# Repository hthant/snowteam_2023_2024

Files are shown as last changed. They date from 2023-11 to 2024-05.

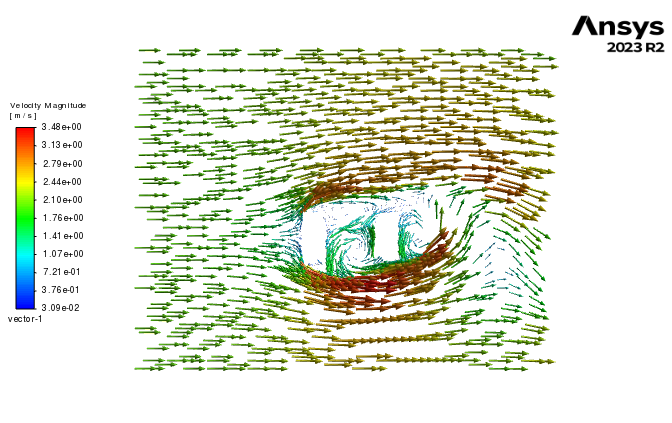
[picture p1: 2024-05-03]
CFD/DPM/DPM 5/DPM Attempt 5_files/progress_files/dp0/FFF-1/Fluent/particle-tracks-1.png

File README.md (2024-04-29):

# Snowteam 2023/2024
Snowflake Team Project Files AY2023_2024

### Summary
  The Machine Learning, Sensing, and Image Processing for Snow Research Senior Design team (Snowflake team) is first repairing the snow measurement and analysis system (SMAS). The SMAS is a device that gathers information on snowflakes and analyzes them using machine learning. This gathers important data including the fall speed of the snowflake and its approximate mass, volume, and density while a snowflake is actively falling. This is accomplished through the high-speed cameras and flashes that are triggered through a system of laser sensors. This data needs to be collected outdoors in harsh winter conditions, so the device must be waterproof and operate at very cold temperatures. This also brings up electrical issues such as providing it with a constant power supply and internet so it continually collects and analyzes data from winter storms. As this is an ongoing project, there is an existing device that is being repaired and improved on from previous years. Additionally, the team is planning the next generation of the SMAS that will be an improvement on the current version. This improvement mainly focuses on a better mechanical design to increase the accuracy of fall speed measurements, as well as improvements on electrical and computer hardware.

### Fall 2023 Semester Team: 
- **Noah Johnson** 
- **Connor Mackell**
- **Kyle Nilsson** 
- **Lauren Rickert**
- **Ryan Zonefeld**

### Spring 2024 Semester Team:
- **Noah Johnson** 
- **Connor Mackell**
- **Kyle Nilsson** 
- **Lauren Rickert**
- **Isai Garcia Zamora**
- **James Sawyer**

### Github Resources
[slides](https://docs.google.com/presentation/d/1HG5fEbkIR5e4xt7H8ZSW351dlRXp_NinHjw-bwELlns/edit?usp=sharing)

[meeting recording](https://drive.google.com/file/d/1aQnVjBFZ8f4g6_dN77DBQdKdTyLpH9qw/view?usp=drive_link)

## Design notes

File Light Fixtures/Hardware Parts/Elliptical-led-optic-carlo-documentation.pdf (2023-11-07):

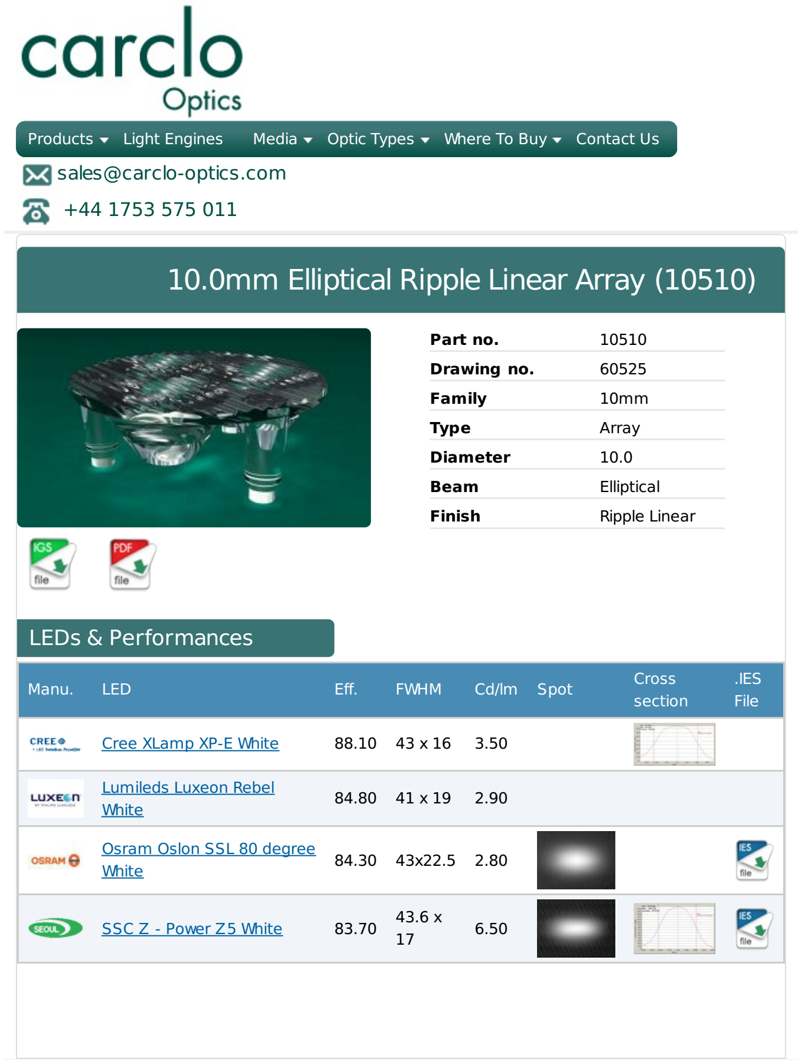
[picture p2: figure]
sales@carclo-optics.com; Part no.; Drawing no.; Family; Type; Array; Diameter; Beam; Elliptical; Finish; Ripple Linear; LEDs & Performances; Manu.; LED; Eff.; FWHM; Cd/lm Spot; Cross section; .IES File; Cree XLamp XP-E White; Lumileds Luxeon Rebel White; Osram Oslon SSL 80 degree White; SSC Z - Power Z5 White; Products; Light Engines; Media; Optic Types; Where To Buy; Contact Us

# 10.0mm Elliptical Ripple Linear Array (10510)

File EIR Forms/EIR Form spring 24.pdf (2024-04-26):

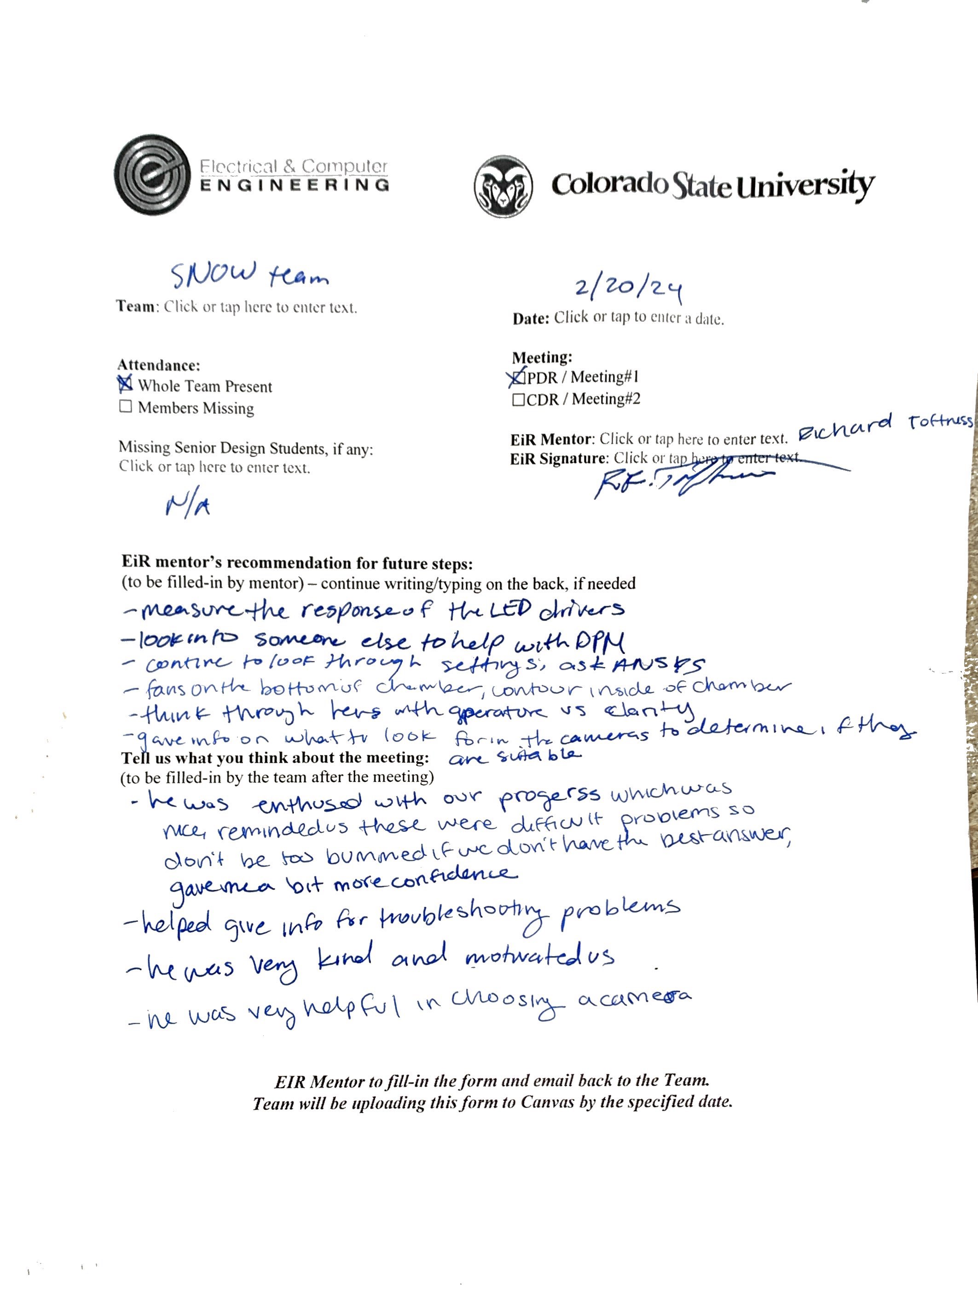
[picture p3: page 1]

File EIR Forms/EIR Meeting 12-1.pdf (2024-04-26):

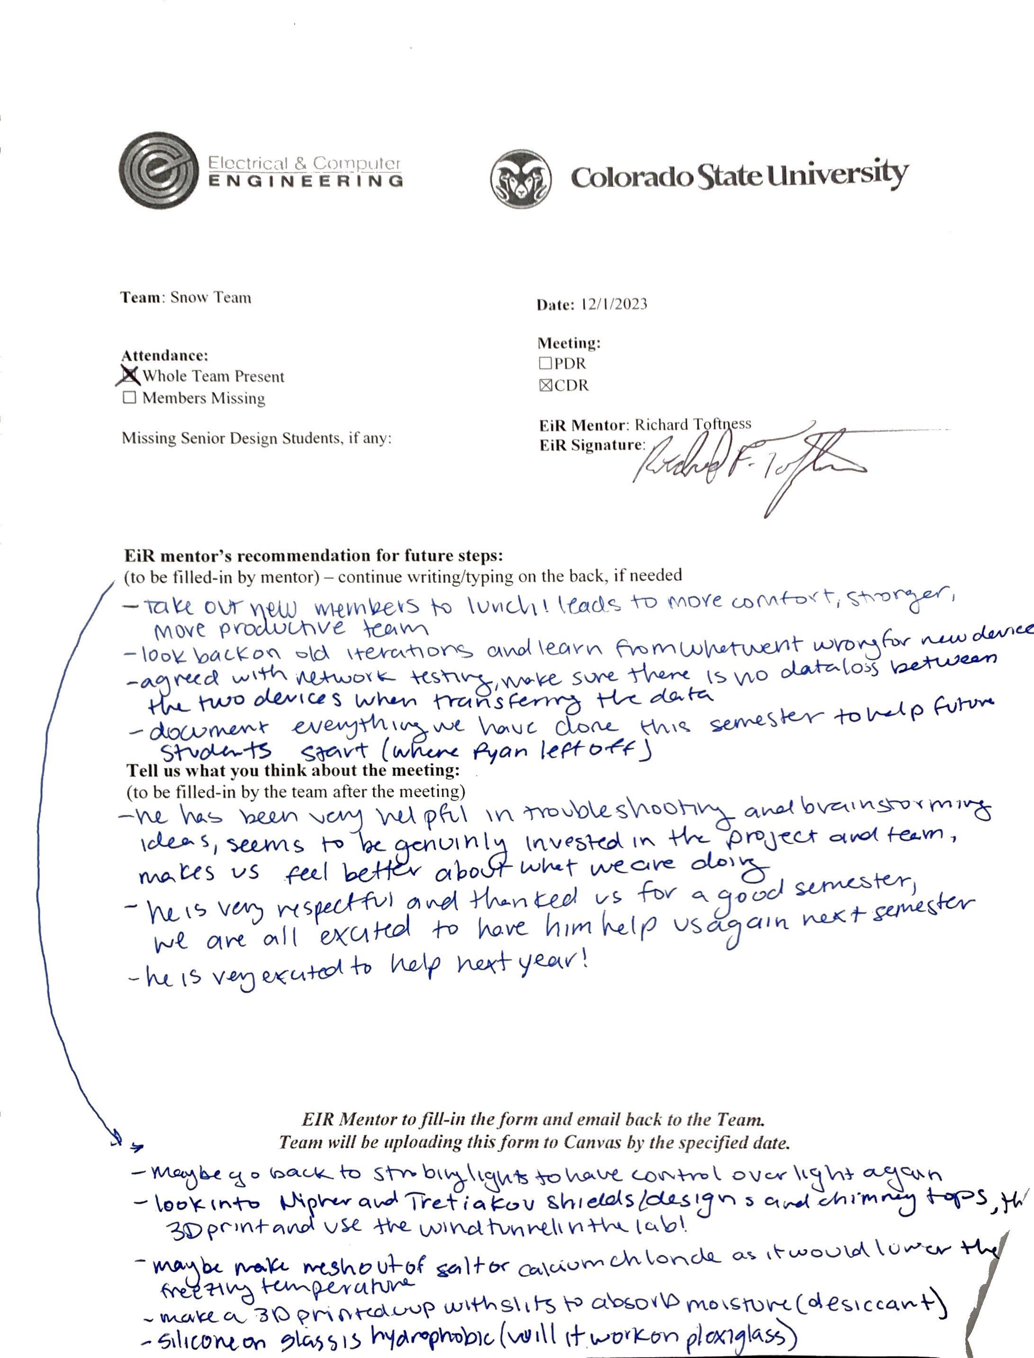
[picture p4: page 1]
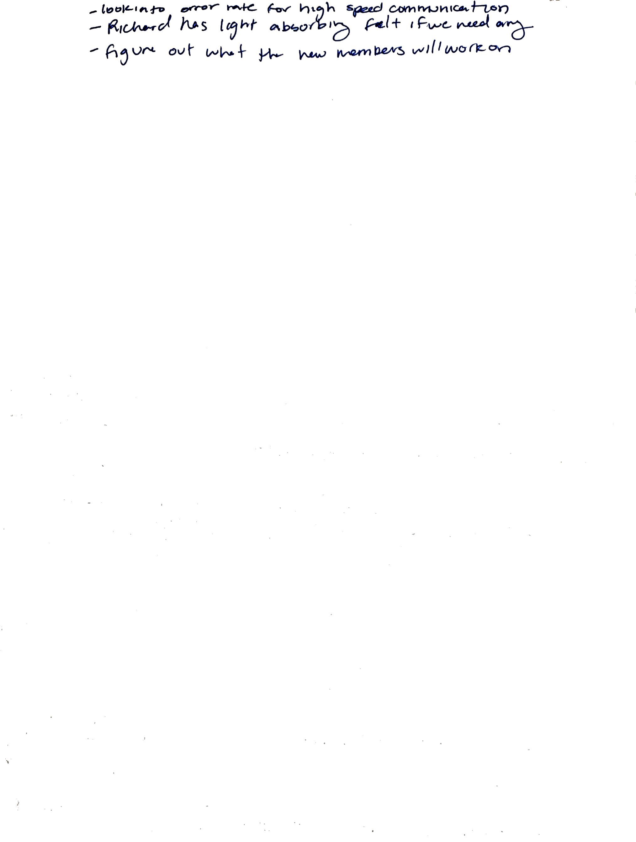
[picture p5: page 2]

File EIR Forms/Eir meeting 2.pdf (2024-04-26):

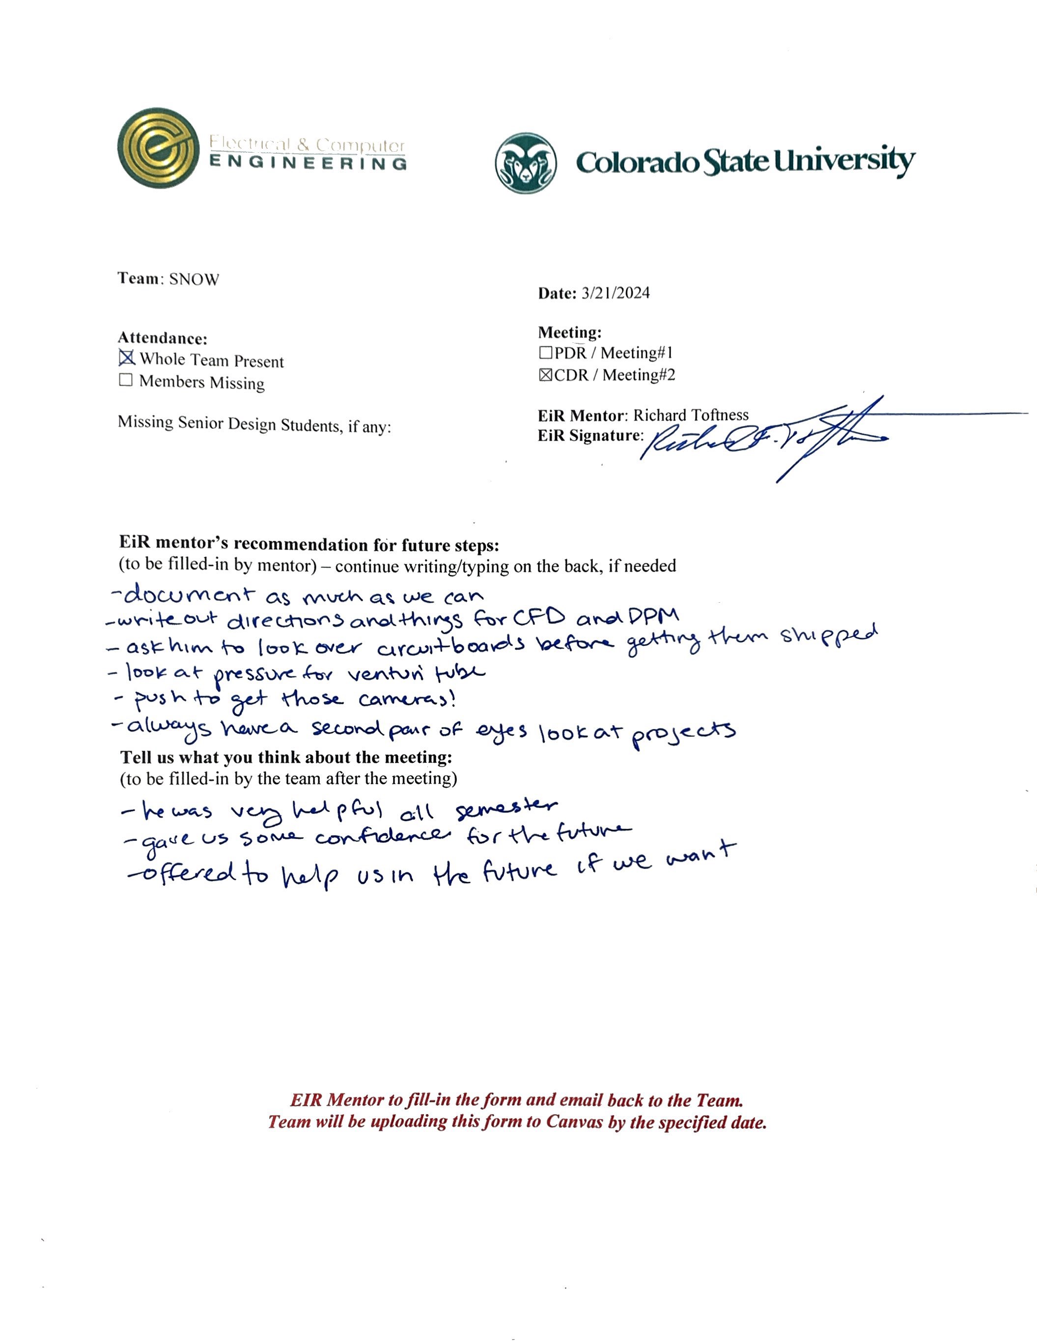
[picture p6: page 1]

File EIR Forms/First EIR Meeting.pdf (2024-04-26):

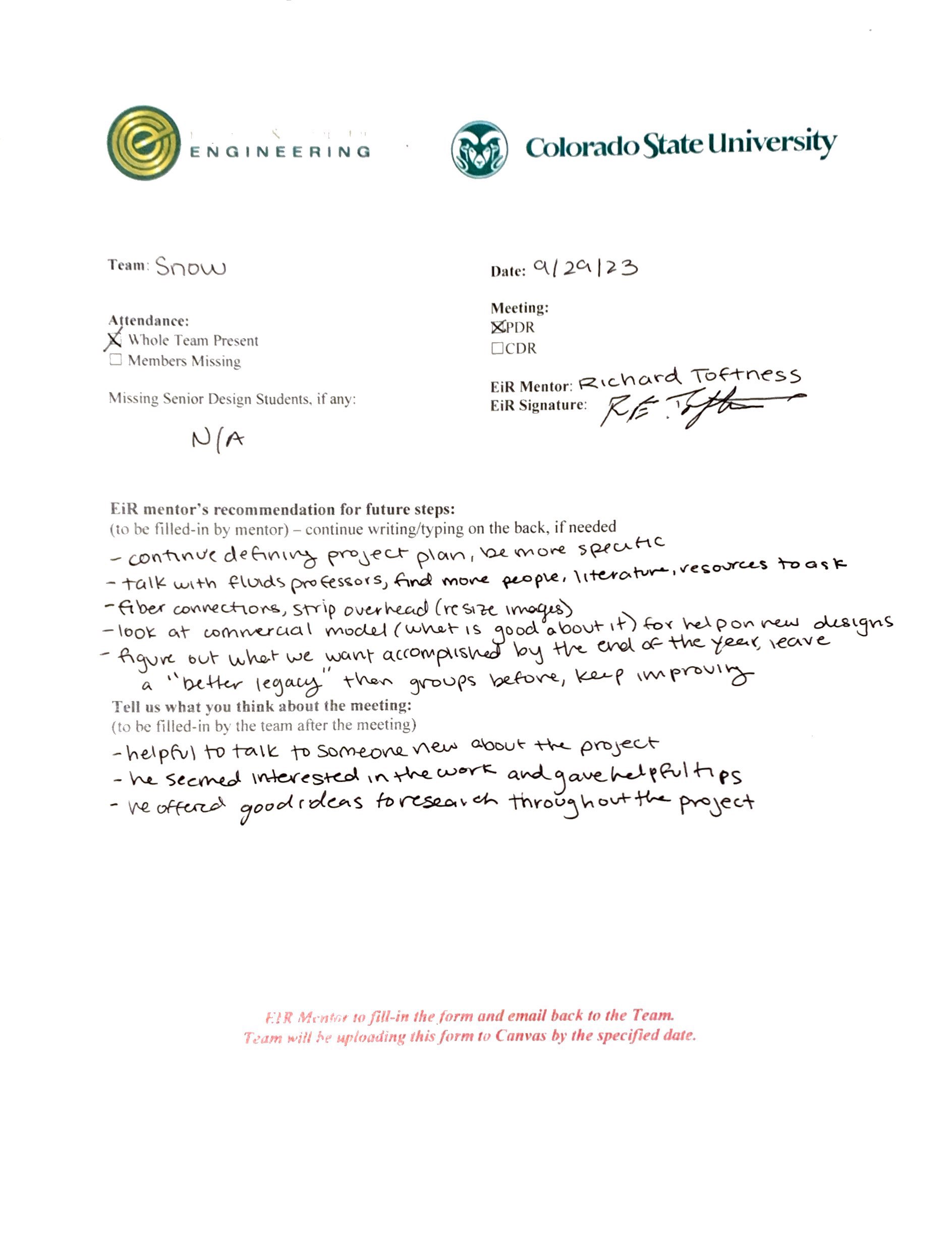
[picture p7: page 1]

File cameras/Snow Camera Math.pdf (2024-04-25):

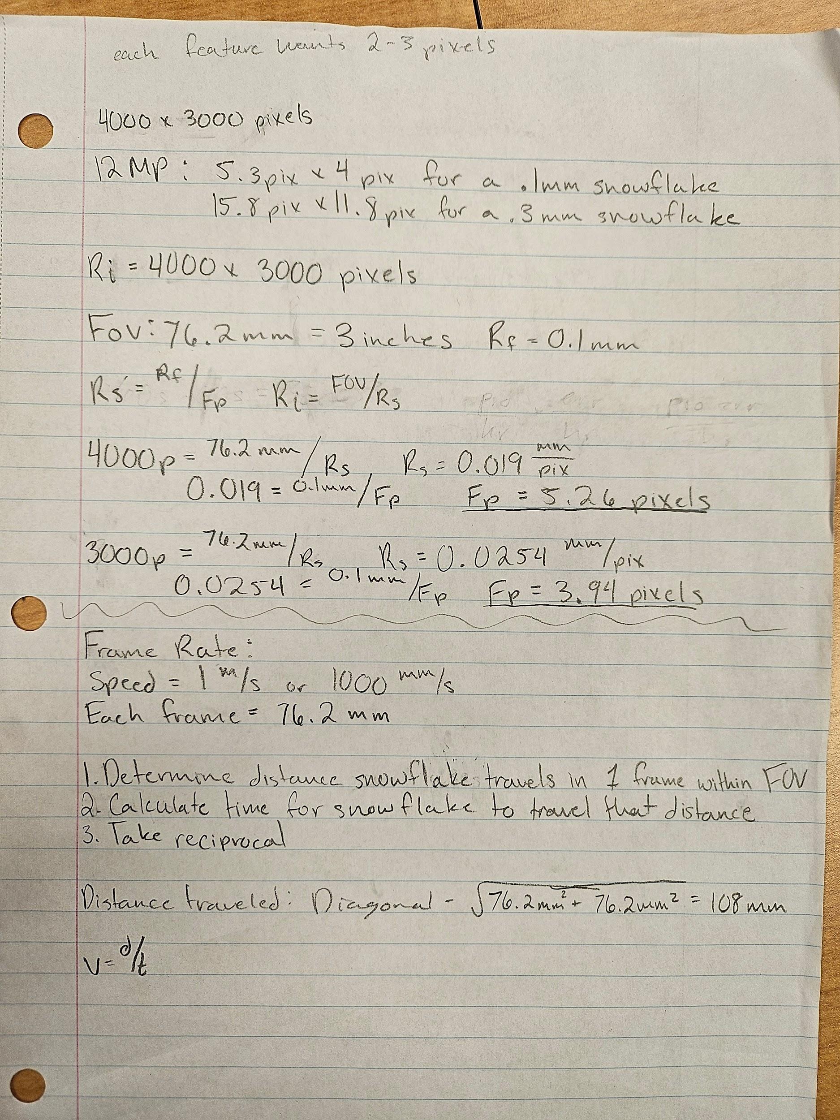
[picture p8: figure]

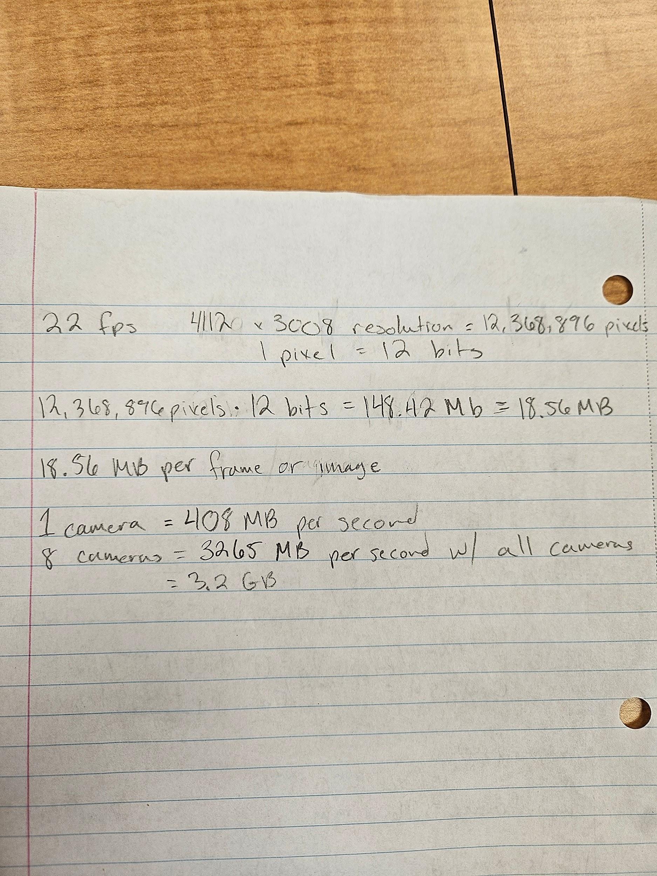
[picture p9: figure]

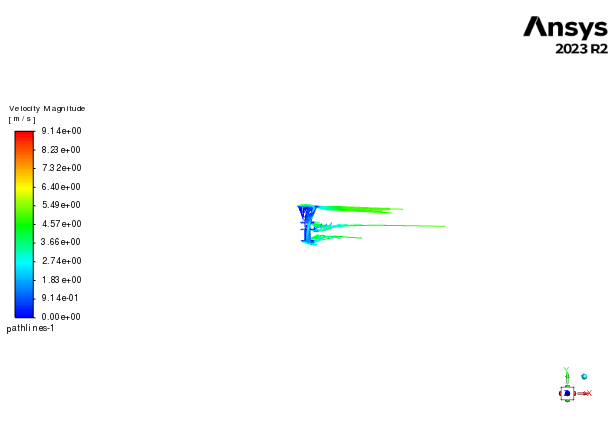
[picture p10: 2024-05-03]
CFD/Conical SMAS Designs/Workbench/Partial_files/progress_files/dp0/FFF-1/Fluent/pathlines-1.png

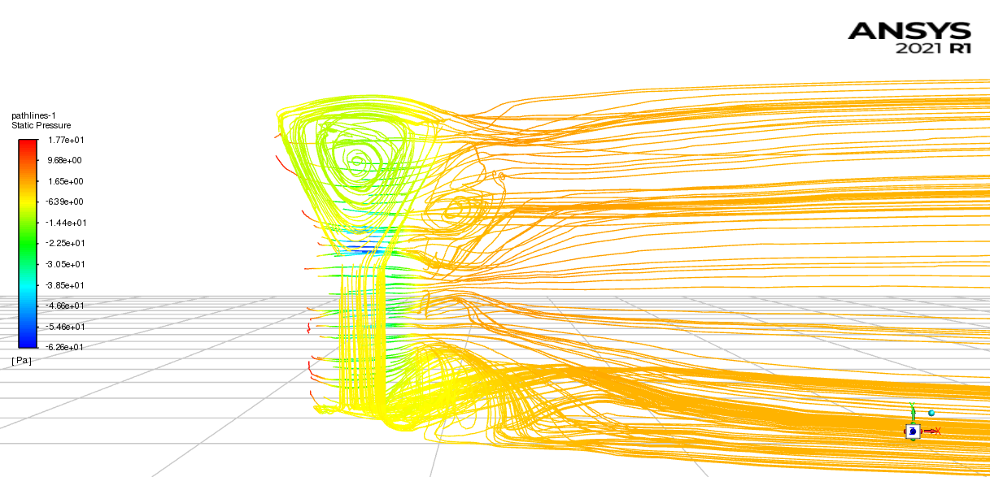
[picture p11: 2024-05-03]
CFD/Conical SMAS Designs/Workbench/Conical_25_degree_SYM_files/dp0/FFF/MECH/Conical_25_degree_SYM_Pressure.png

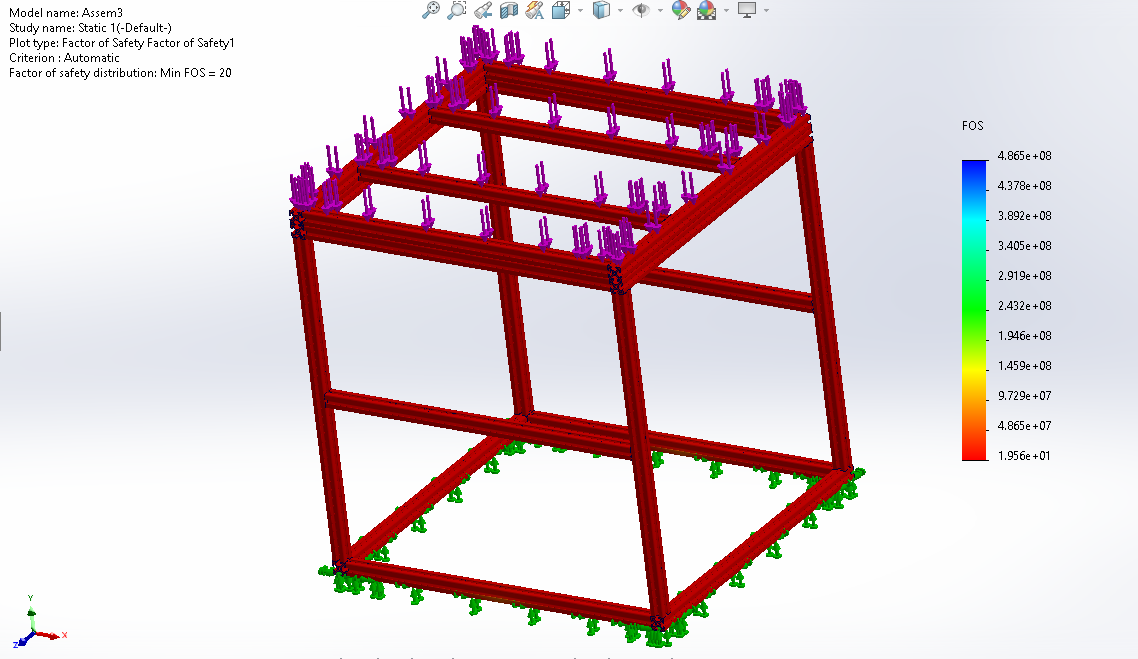
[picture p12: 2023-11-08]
solidworks_senior_design/safetyfactor8020_1.0inch.PNG

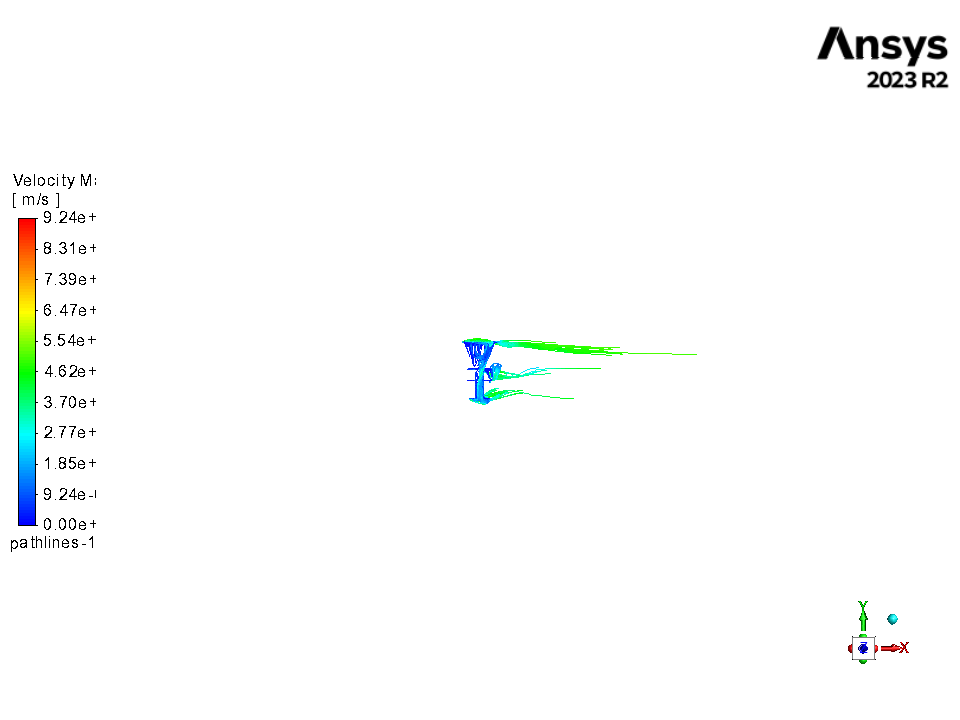
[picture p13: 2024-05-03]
CFD/Conical SMAS Designs/Workbench/Conical_20_degree_SYM_files/progress_files/dp0/FFF-1/Fluent/pathlines-1.png

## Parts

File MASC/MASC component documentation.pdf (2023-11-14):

Part types and numbers:
3 48 V power supplies : CFM70S480
12 V power supply: CFM70S120
Datasheet: https://www.componentsbureau.com/assets/product_files/cfm70s_datasheet.pdf Female housings for power supplies: VHR-3N & VHR-4N
Datasheet: https://www.jst-mfg.com/product/pdf/eng/eVH.pdf
Crimps for power supplies: SVH-41T-P1.1
Connecter for 12V power splitter: 0397730002
Datasheet: https://tools.molex.com/pdm_docs/sd/397730002_sd.pdf 22 AWG wire for power supply connections

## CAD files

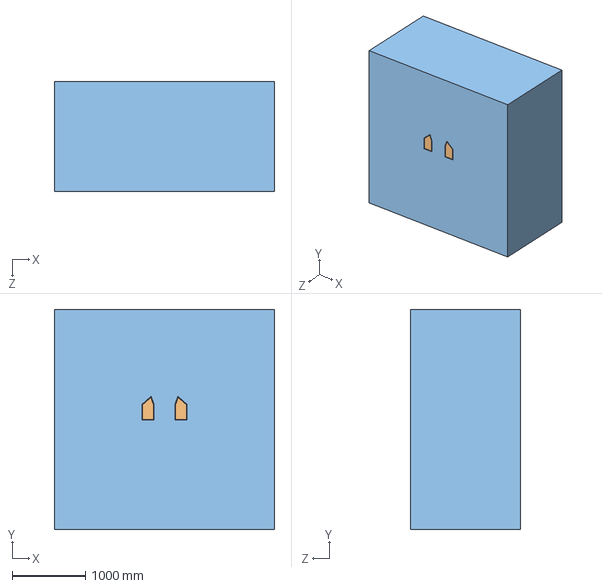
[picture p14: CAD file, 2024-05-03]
CFD/FebruaryBasicDesign/newdesignstraightupfullangle.STEP
3000.0 x 3000.0 x 1500.0 mm

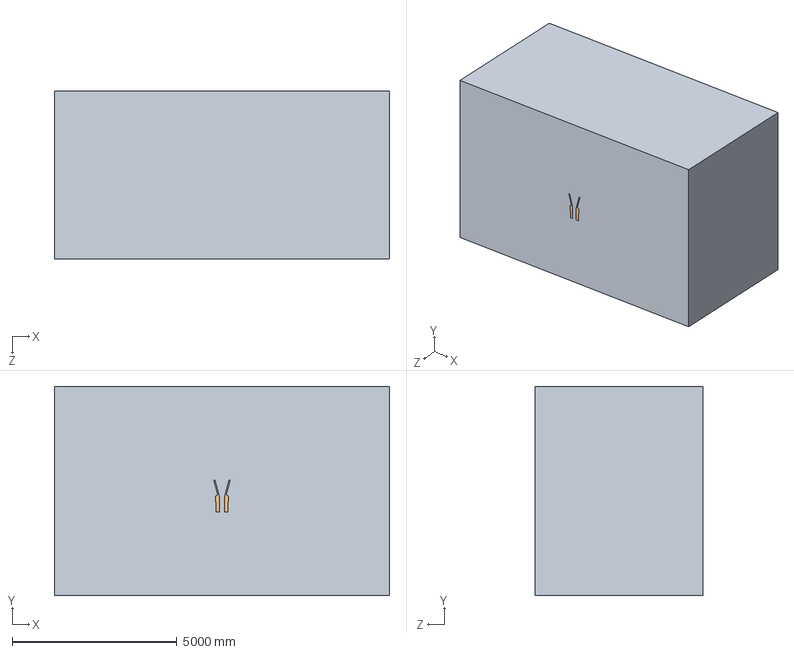
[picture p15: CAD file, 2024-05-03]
CFD/Conical SMAS Designs/Solidworks/Conical_15_degree_SYM.STEP
10160.0 x 6350.0 x 5080.0 mm

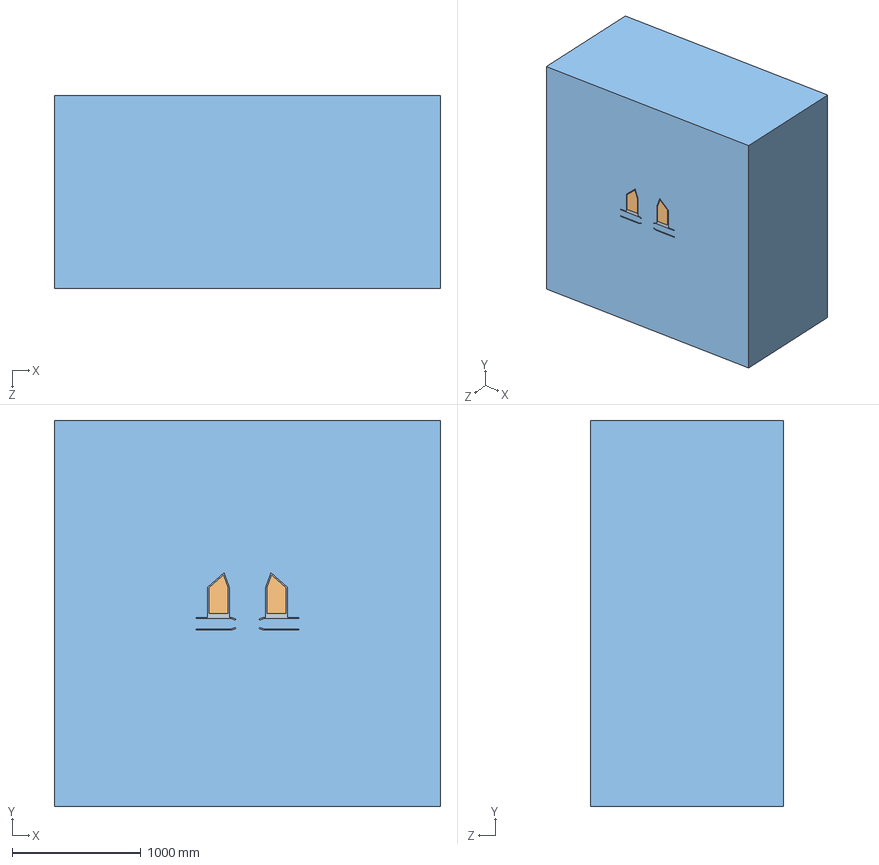
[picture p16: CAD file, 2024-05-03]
CFD/Venturi Tube/VenturiTube2.STEP
3000.0 x 3000.0 x 1500.0 mm

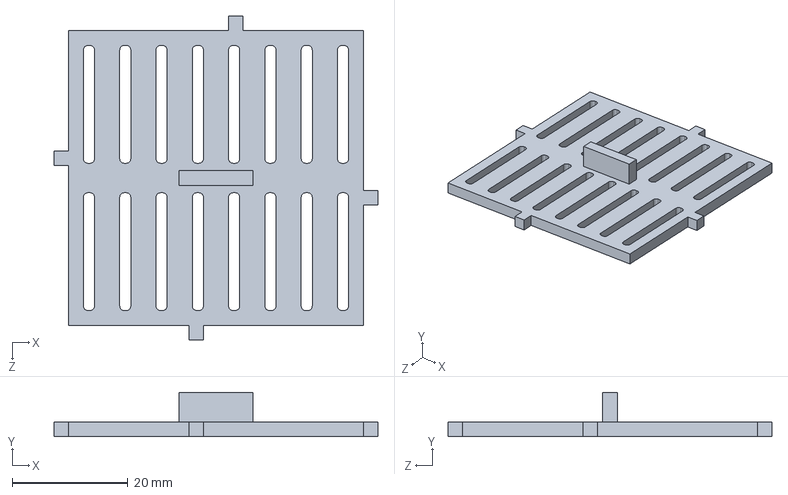
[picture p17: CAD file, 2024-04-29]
Desiccant Box/DesiccantBoxLid.SLDPRT
55.9 x 7.62 x 55.9 mm

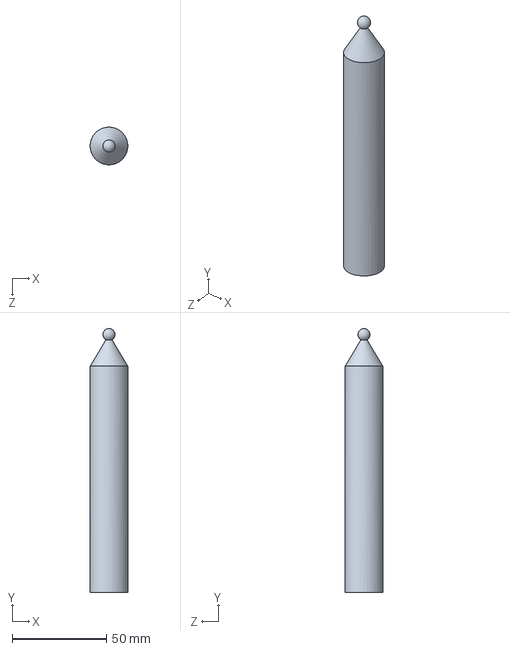
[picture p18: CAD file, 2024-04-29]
LED Pen/BasicPen.SLDPRT
20.0 x 140.0 x 20.0 mm

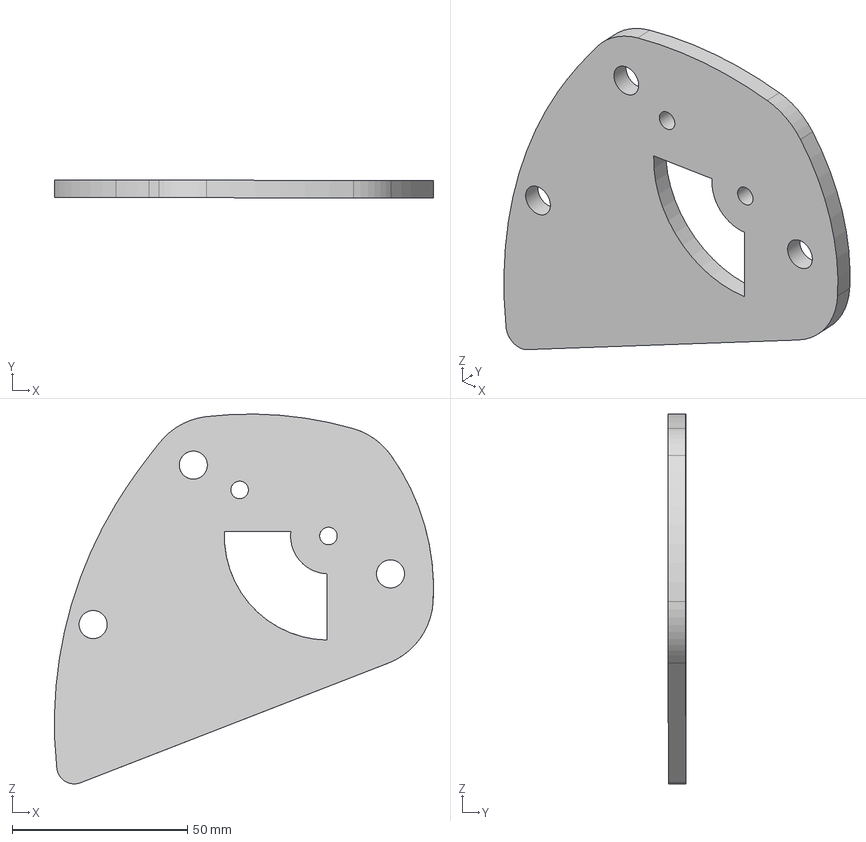
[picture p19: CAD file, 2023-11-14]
Light Fixtures/LED Bracket CAD Files/Diagnal LED Bracket - 1 side.step
108.0 x 5.26 x 105.4 mm

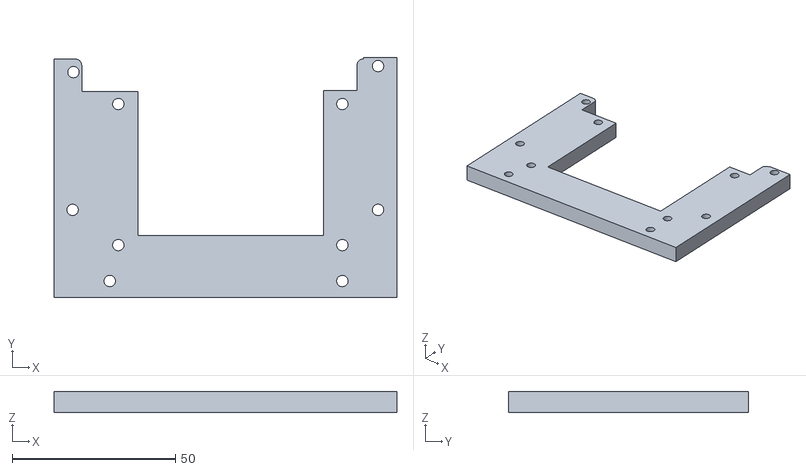
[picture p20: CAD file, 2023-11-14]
MASC/3D drawings/Power_supply_3rd_try v3.stl
105.0 x 73.4 x 6.50

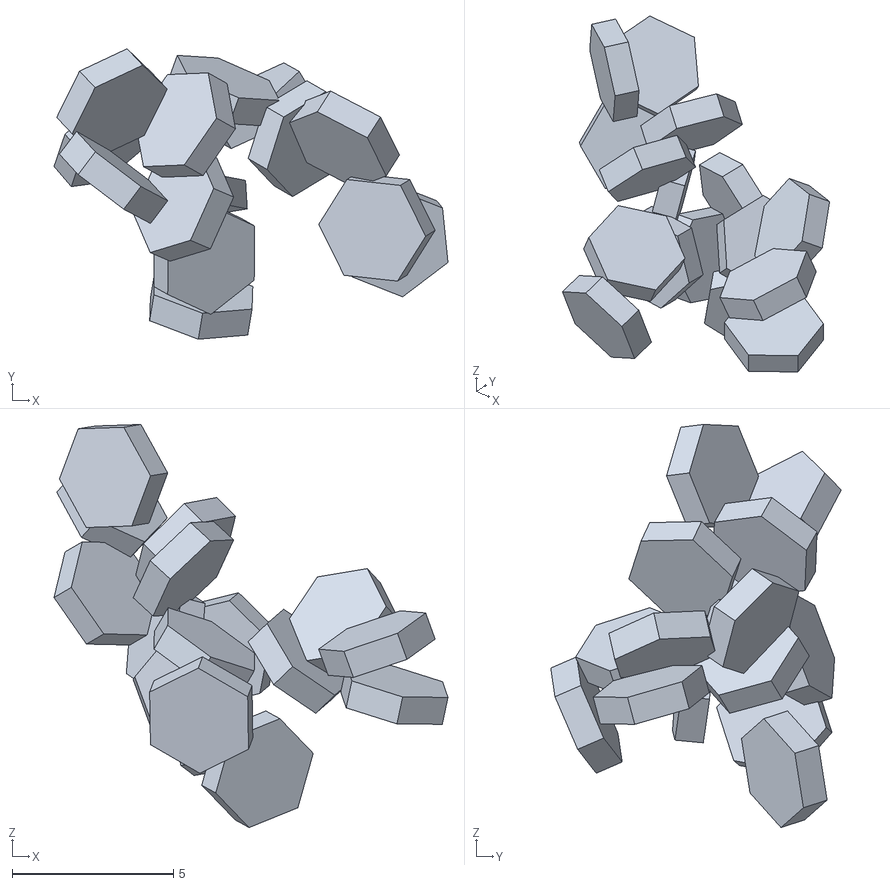
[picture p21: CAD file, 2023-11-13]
Resin Printing/Snowflakes/3D_Files/Ag,12.5,P1.stl
12.2 x 9.01 x 12.5

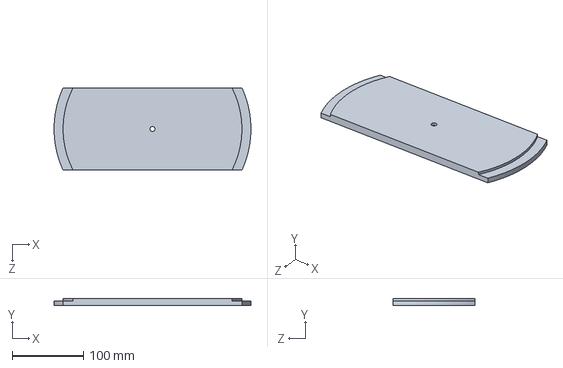
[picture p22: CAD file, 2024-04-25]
solidworks_senior_design/realignment_tool.SLDPRT
276.1 x 9.53 x 114.3 mm

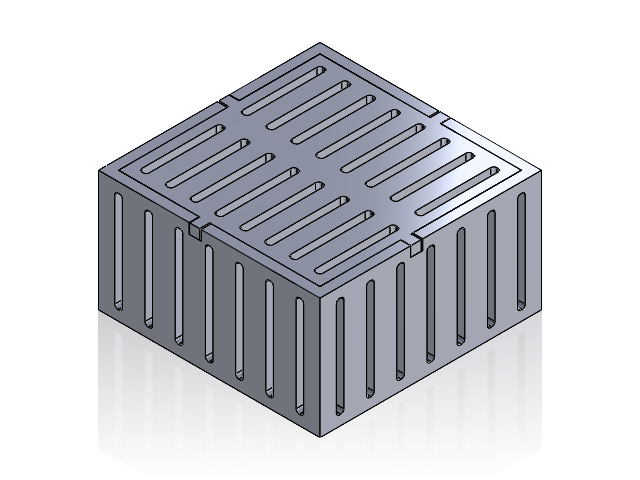
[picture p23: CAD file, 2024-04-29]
Desiccant Box/DesiccantBoxAssem.SLDASM
DesiccantBoxLid
DesiccantBox

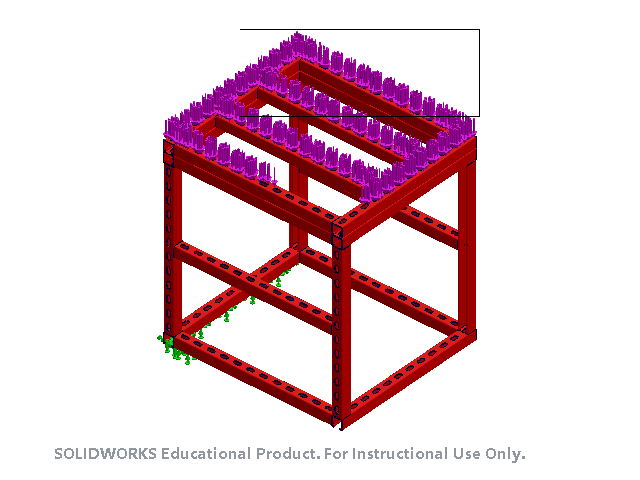
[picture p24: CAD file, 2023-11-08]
solidworks_senior_design/strut1baseandtop.SLDASM
1.625 x 2Ft Strut Channel x 20

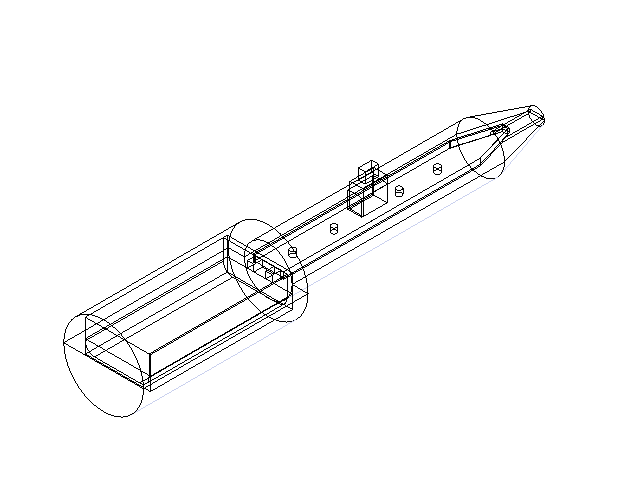
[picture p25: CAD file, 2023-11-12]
LED Pen/PenAgainAssembly.SLDASM
PenAgainSide2
CircuitBoard
BatteryPack
PenAgain

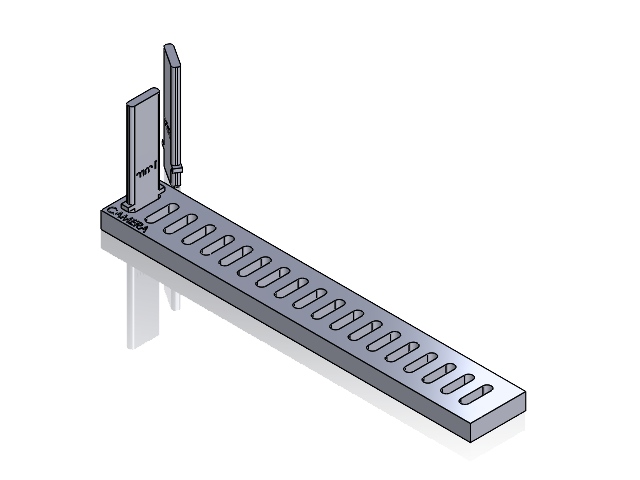
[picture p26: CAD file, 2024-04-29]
Spot Size Part/SpotSizeAssem.SLDASM
Base
stick1mmdiam
stick2mmdiam

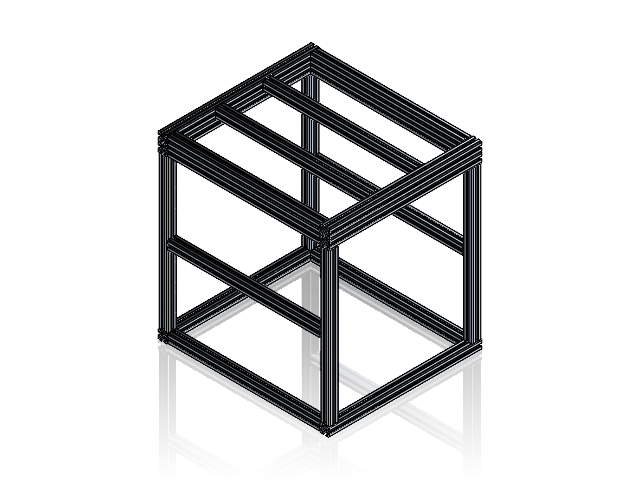
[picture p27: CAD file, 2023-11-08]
solidworks_senior_design/8020_1.5inchbaseandtop.SLDASM
8020_1.5inchbeam x 20

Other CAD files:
solidworks_senior_design/assemblybaseandtop.SLDASM
solidworks_senior_design/8020_1.0inchbaseandtop.SLDASM
CFD/Models for CFD/20Degree_8_5inch_inner_diameter.STEP
CFD/withfins/newdesignwithfins.STEP
CFD/Conical SMAS Designs/Solidworks/Conical_0_degree.SLDPRT
CFD/Conical SMAS Designs/Solidworks/Conical_0_degree.STEP
CFD/Conical SMAS Designs/Solidworks/Conical_15_degree.SLDPRT
CFD/Conical SMAS Designs/Solidworks/Conical_20_degree.SLDPRT
CFD/Conical SMAS Designs/Solidworks/Conical_20_degree.STEP
CFD/Conical SMAS Designs/Solidworks/Conical_20_degree_ROUGH.SLDPRT
CFD/Conical SMAS Designs/Solidworks/Conical_20_degree_ROUGH.STEP
CFD/Conical SMAS Designs/Solidworks/Conical_25_degree.SLDPRT
CFD/Conical SMAS Designs/Solidworks/Conical_25_degree_SYM.STEP
CFD/Conical SMAS Designs/Solidworks/Conical_45_degree.SLDPRT
CFD/Conical SMAS Designs/Solidworks/Conical_45_degree.STEP
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

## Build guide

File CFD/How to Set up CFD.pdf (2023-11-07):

Setup for CFD:
1. Import geometry
2. Generate mesh
Create named selections
a. Symmetry
b. Walls
c. Inlet
d. Outlet
e. Chamber: hide domain geometry, face selection, box select chamber

3.

4. Check mesh
5. Quality mesh check (orthogonal quality should be above 0.1)
General
a. Steady time

6.

Models
a. Energy equation on
b. Transition SST (combines k epsilon and k omega)

7.

Materials
a. Fluid: air -> constant density

8.

Boundary conditions
Inlet: velocity = 2m/s, 5m/s, 10m/s, thermal = 263.15K (-10C average air temp in deployment area)

a.

b. Outlet: pressure = 0Pa, thermal = 263.15k
c. Walls: moving wall -> speed = 2m/s, 5m/s, 10m/s, x-direction=1, no-slip

9.

10. Methods: SIMPLEC
Report definitions
a. New force report: force -> zones: chamber, report file, report plot
New flux report: mass flow rate -> zones: inlet and outlet, report file, report plot (to determine steady state)

b.

11.

Initialization
a. Standard
b. Gauge pressure: 0Pa
c. X velocity: 2m/s, 5m/s, 10m/s

12.

# 11/1/23 - How to set up CFD

Wednesday, November 1, 2023 11:10 AM

Run calculation
a. 500 iterations

13.

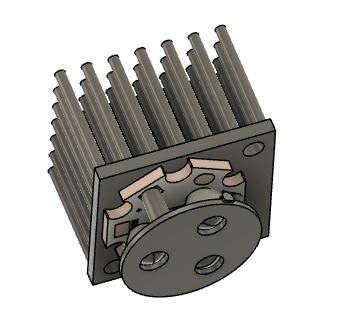
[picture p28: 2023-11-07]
Light Fixtures/Heatsink/Heatsink assembly.png

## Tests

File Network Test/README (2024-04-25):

tx2.cc is c++ code for network tests

ethConnect.sh pulls files from a remote device and copies them to your local device. Can change for loop to change amount of iterations.
time.sh times ethConnect.sh and outputs the speed of the transfer and seocnds and the file size.

ethConnectRemote.sh pushes files from a remote location to a local device you want to store all the files on. Run time.sh on it to time the network transfer.

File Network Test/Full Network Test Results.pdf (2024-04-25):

Full Network Test
Description | Times Run | Size | MTU value | Time (s)
cropped_packets | 1 | 15Mb | 1500 | 8.292
| | | 2000 | 8.286
| | | 3000 | 8.132
| | | 4000 | 8.240
| | | 5000 | 8.190
| | | 6000 | 8.157
| | | 7000 | 8.278
| | | 8000 | 8.081
| | | 9000 | 8.265
cropped_packets | 10 | 150Mb | 1500 | 16.267
| | | 2000 | 16.103
| | | 3000 | 16.309
| | | 4000 | 16.346
| | | 5000 | 16.211
| | | 6000 | 16.287
| | | 7000 | 16.169
| | | 8000 | 16.249
| | | 9000 | 16.604
cropped_packets | 30 | 448Mb | 1500 | 35.976
| | | 2000 | 36.278
| | | 3000 | 34.421
| | | 4000 | 34.635
| | | 5000 | 34.680
| | | 6000 | 34.793
| | | 7000 | 35.094

| | | 8 0 0 0 | 3 5.0 4 7
| | | 9 0 0 0 | 3 5.7 3 1
f ull | 1 | 1 1 1 M b | 1 5 0 0 | 9.3 7 6
| | | 2 0 0 0 | 9.3 8 9
| | | 3 0 0 0 | 9.3 8 1
| | | 4 0 0 0 | 9.3 8 3
| | | 5 0 0 0 | 9.4 6 1
| | | 6 0 0 0 | 9.3 5 0
| | | 7 0 0 0 | 9.4 9 0
| | | 8 0 0 0 | 9.6 1 5
| | | 9 0 0 0 | 1 2.2 3 5
f ull | 1 0 | 1.1 G b | 1 5 0 0 | 2 7.2 5 6
| | | 2 0 0 0 | 2 7.2 4 9
| | | 3 0 0 0 | 2 7.4 1 2
| | | 4 0 0 0 | 2 7.5 4 7
| | | 5 0 0 0 | 2 7.2 2 4
| | | 6 0 0 0 | 2 6.4 2 9
| | | 7 0 0 0 | 2 7.6 7 6
| | | 8 0 0 0 | 2 7.7 1 7
| | | 9 0 0 0 | 5 7.7 1 2
M o d d e d -c si | 1 | 1.2 G b | 1 5 0 0 | 2 4.5 9 7
| | | 2 0 0 0 | 2 3.3 8 6
| | | 3 0 0 0 | 2 4.8 9 1
| | | 4 0 0 0 | 2 4.2 9 8
| | | 5 0 0 0 | 2 4.3 8 3
| | | 6 0 0 0 | 2 5.1 3 6
| | | 7 0 0 0 | 2 5.2 3 1

| | | 8 0 0 0 | 2 5.2 9 7
| | | 9 0 0 0 | 5 6.2 5 3
M o d d e d -c si | 2 | 2.3 G b | 1 5 0 0 | 4 2.0 1 3
| | | 2 0 0 0 | 4 1.8 5 7
| | | 3 0 0 0 | 4 0.6 7 7
| | | 4 0 0 0 | 4 1.7 1 4
| | | 5 0 0 0 | 4 2.9 9 2
| | | 6 0 0 0 | 4 1.0 7 2
| | | 7 0 0 0 | 4 1.1 9 6
| | | 8 0 0 0 | 4 1.1 4 4
| | | 9 0 0 0 | 1 0 4.8 6 7

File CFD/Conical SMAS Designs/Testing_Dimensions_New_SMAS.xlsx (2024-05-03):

Conical SMAS Device |  |  |  |  |  |  |  | Pipe Length (in) | 18
Base |  |  | Lid
Height (in) | ID (in) | OD (in) | Height | Upper Diameter | Lower Diamter | Angle | Angle Radians
18 | 6 | 14 | 18 | 6 | 6 | 0 | 0
18 | 6 | 14 | 17.93150457 | 9.137606739 | 6 | 5 | 0.0872664626
18 | 6 | 14 | 17.72653955 | 12.2513344 | 6 | 10 | 0.1745329252
18 | 6 | 14 | 17.38666487 | 15.31748562 | 6 | 15 | 0.2617993878
18 | 6 | 14 | 16.91446717 | 18.31272516 | 6 | 20 | 0.3490658504
18 | 6 | 14 | 16.31354017 | 21.21425742 | 6 | 25 | 0.436332313
18 | 6 | 14 | 15.58845727 | 24 | 6 | 30 | 0.5235987756
18 | 6 | 14 | 14.7447368 | 26.64875171 | 6 | 35 | 0.6108652382
18 | 6 | 14 | 13.78879998 | 29.14035395 | 6 | 40 | 0.6981317008
18 | 6 | 14 | 12.72792206 | 31.45584412 | 6 | 45 | 0.7853981634
18 | 6 | 14 | 11.57017697 | 33.57759995 | 6 | 50 | 0.872664626
18 | 6 | 14 | 10.32437585 | 35.48947359 | 6 | 55 | 0.9599310886
18 | 6 | 14 | 9 | 37.17691454 | 6 | 60 | 1.047197551
18 | 6 | 14 | 7.607128711 | 38.62708033 | 6 | 65 | 1.134464014
18 | 6 | 14 | 6.15636258 | 39.82893435 | 6 | 70 | 1.221730476
18 | 6 | 14 | 4.658742812 | 40.77332975 | 6 | 75 | 1.308996939
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

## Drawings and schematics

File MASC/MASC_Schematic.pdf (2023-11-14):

↳

In | infrared ? Sensor | E

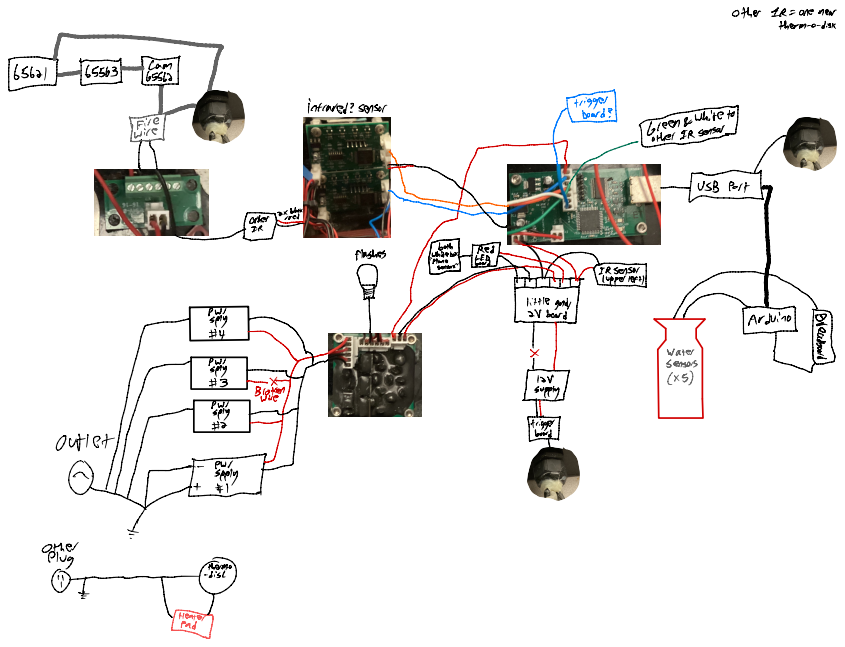
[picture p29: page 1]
other eR= one new there-o-disk; trigger board ?; wire; other; R sensor; E US Port; Kona); error; flashes; ri unbee--Es>-; -~sensor; -zV bowd; Erine I; Worsees; ↳Gem

Gro & whit to ↳

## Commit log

2023-11-07 Add files via upload
    Updated Heatsink Specs and hardware
2023-11-12 Add files via upload
    CFD lip, diffuser, old
    [DesignPointLog.csv]
2023-11-12 All pen from final print
    [BatteryPack.SLDPRT, BatteryPack.STL, CircuitBoard.SLDPRT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]
2023-11-13 3D files for snowflakes
    [Ag,1,St100.stl, Ag,1,St18.stl, Ag,1.25,St100.stl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]
2023-11-14 3D Drawings
    [CornerPowerSupplyVfinal v0.stl, Power_supply_3rd_try v3.stl]
2023-11-14 Added MASC schematic
    [CornerPowerSupplyVfinal v0.stl, Power_supply_3rd_try v3.stl]
2023-11-14 Corbin's trigger board
    [camera_trigger.kicad_sch]
2023-11-14 Add files via upload
    Added CAD Step files
    [Horizontal LED Bracket no laser v1.step, Horizontal LED Bracket v1.step, LEDHolder v1.step]
2023-11-14 Add files via upload
    Missed one
    [Diagnal LED Bracket - 1 side.step]
2023-12-04 Script to ping devices
2024-04-25 Create Cameras File
2024-04-25 Camera math pdf
2024-04-25 Rename AllSnowflakesSliced.chitubox to Resin Printing/AllSnowflakesSliced.chitubox
    change folder
2024-04-26 Rename SnowFlake_Ag.chitubox to Resin Printing/SnowFlake_Ag.chitubox
    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
2024-04-26 Rename All_snowflakes.chitubox to Resin Printing/All_snowflakes.chitubox
    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
2024-05-03 more DPM folders
    [Ag,1,St100.stl, Ag,1,St18.stl, Ag,1.25,St100.stl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]
2024-05-03 CFD folders
    [20Degree_7_5inch_inner_diameter.SLDPRT, 20Degree_7_5inch_inner_diameter.STEP, 20Degree_8_5inch_inner_diameter.SLDPRT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]
